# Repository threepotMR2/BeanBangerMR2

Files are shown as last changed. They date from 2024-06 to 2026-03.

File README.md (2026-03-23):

BeanBangerMR2
=============

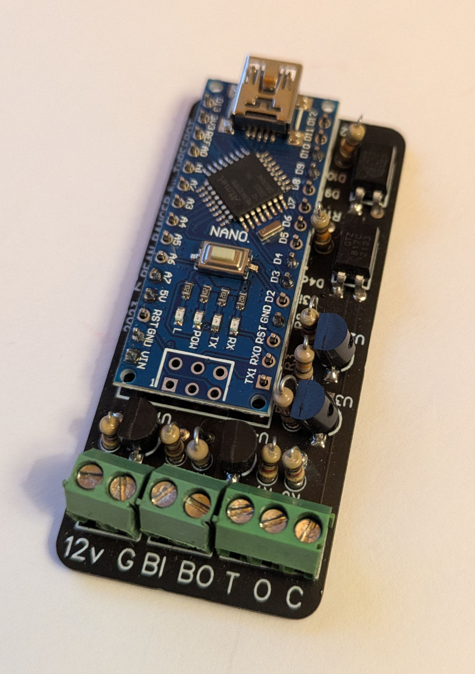
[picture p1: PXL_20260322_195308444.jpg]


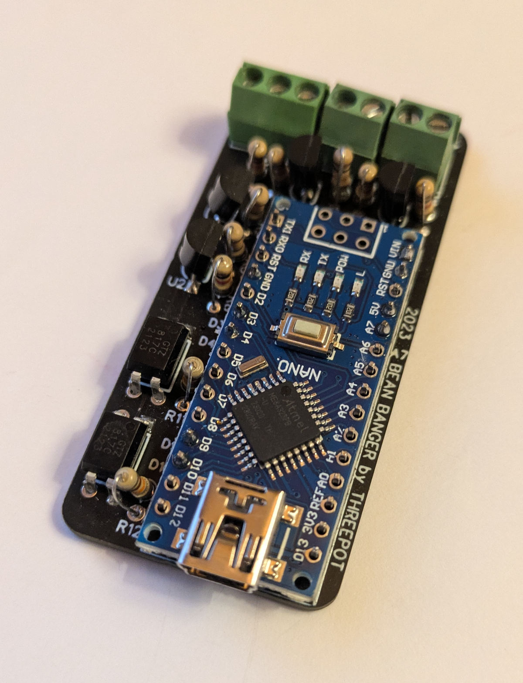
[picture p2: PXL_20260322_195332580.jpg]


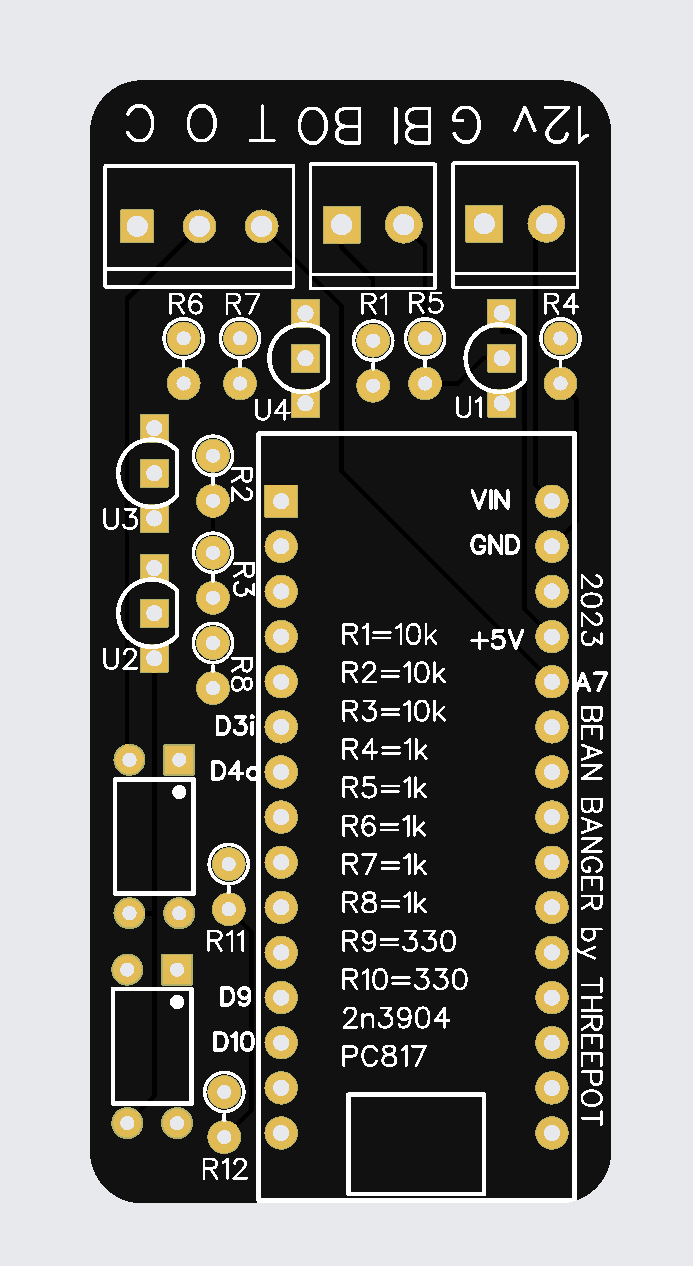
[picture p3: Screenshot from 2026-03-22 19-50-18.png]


This is an adaption/fork for the BeanMPX project by fiztech-code - thank you for amazing work, this would not exist without you. I have no idea what I'm doing but have butched the BeanMPX project to make this do what it should. It is probably the worst code man has seen, and I am probably using Github in totally the wrong way. Please forgive my stupidity and ignorance!

All you need is in the BeanBangerMR2 folders, one is the arduino project, the other is the gerber/bom for the PCB.

1) Simply upload the gerber to pcbway or jlcpcb and get some made for peanuts.
2) The list of components you need is printed on the circuit board and its all though hole easy soldering
3) upload the arduino sketch to the arduino nano
4) wire in the wire from the alternator charge sense line, the oil pressure switch, take a spur from the temp sensor, 12v, ground and the bean wires (either way doesn't matter).

Then as soon as you turn on the car, the warning lights will works and the temp gauge works.

Here is some testing video footage and description of usage:-
https://www.youtube.com/watch?v=NijV0-c2hg0

You will see it completed here:-
https://www.youtube.com/shorts/5FSTMIWvpoY

There is a very messy spreadsheet that "helps" to make the formula for to convert the analogue input voltage to the BEAN temp hex value for the arduino sketch so you can calibrate it for different temp sensors and ecu combinations.

Enjoy! 

ThreepotMR2

Components list:-

3 x 10k resistors
5 x 1k resistors
2 x 330 ohm resistors
4 x 2n3904 transistors
2 x PC817 optocouplers
1 x arduino nano
Some 2.54mm pitch PCB Mount Screw Terminal blocks ... or just solder your wires direct to the PCB

How To wire it in
=================

Inside the cluster the MPX1 and MPX2 wires are both joined together, so you can use either or both! The do the same thing.

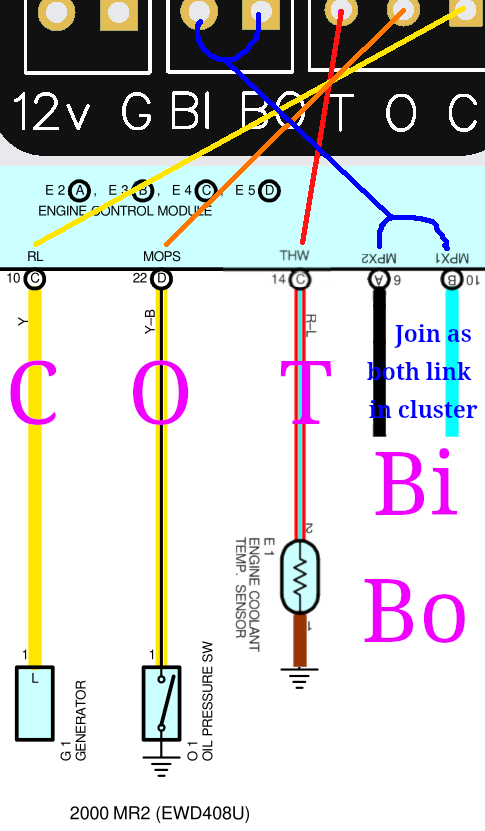
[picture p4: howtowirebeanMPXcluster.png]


This diagram shows you what each wire to use from the MR2 engine ecu connector.

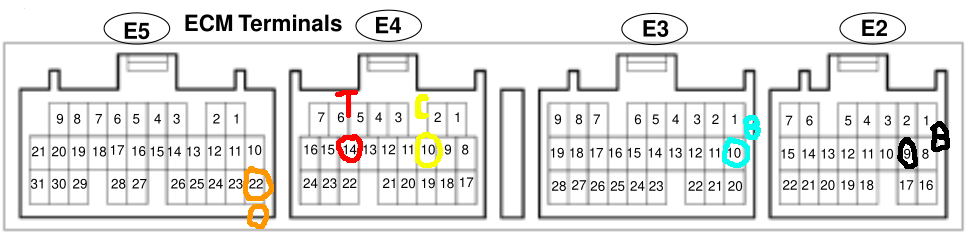
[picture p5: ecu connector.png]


BUT it you need to wire the temp sensor to your current ECU, which has a pullup resistor in it and thus the beanbanger works if you pull a spur from your temp sensor. e.g. your temp sensor will be feeding both the beanbanger and your engine ecu. The temp gauge calibration supplied in the arduino code is for Ecumaster Emu Black which has a 2.2k pull up resistor.

How To Calibrate te temp gauge algo for different sensor and ecu combinations
=============================================================================

In the "BeanBanger_works.ino" file this is this bit of code on lines 42 to 45

      //Does the temp gauge Algo is 75000/(ADC+300)).... ADC 0-1023 is 0-5v
      //Engine Temp Gauge moves 90-255 but normal range deadzone 165-212
      t = analogRead(A7);  //read temp sensor voltage on analogue pin 2  
      t = 75000/(t+300);

We are reading the analog value from the ADC Value from arduino input pin "A7", then we do a bit of maths on it:-

75000 / ( ADC value + 300) = bean temp value

You can play with this maths to create a value which ranges from 90 to 255 which is the gauge needle possition.

So roughly Degrees C x 2 = Bean value ......... e.g. 90c x 2 = 180 = which is in the "dead zone" being normal.

Its weird though, the first value that makes it move is 45c (90 bean) then upto 165 bean (82c) upto the middle of the gauge, then there is a deadzone from 165 to 212 which is normal temperature, then if you go about this the needle shoots up quickly. Its not a direct gauge, its more of an needle based normal/overheating dash indicator.

The deadzone starts at 82.5c (165 bean) and goes upto 106c (212 bean) which is pretty reasonable. Anything above this makes the gauge shoot up, e.g 107c = 214 bean

There is a spreadsheet here called temp gauge algo.ods https://github.com/threepotMR2/BeanBangerMR2/blob/master/temp%20gauge%20algo.ods which is an absolute utter mess but if you play with it you will see it draws you some graphs and will let you experiement with your algo, it is truly an utter mess though.

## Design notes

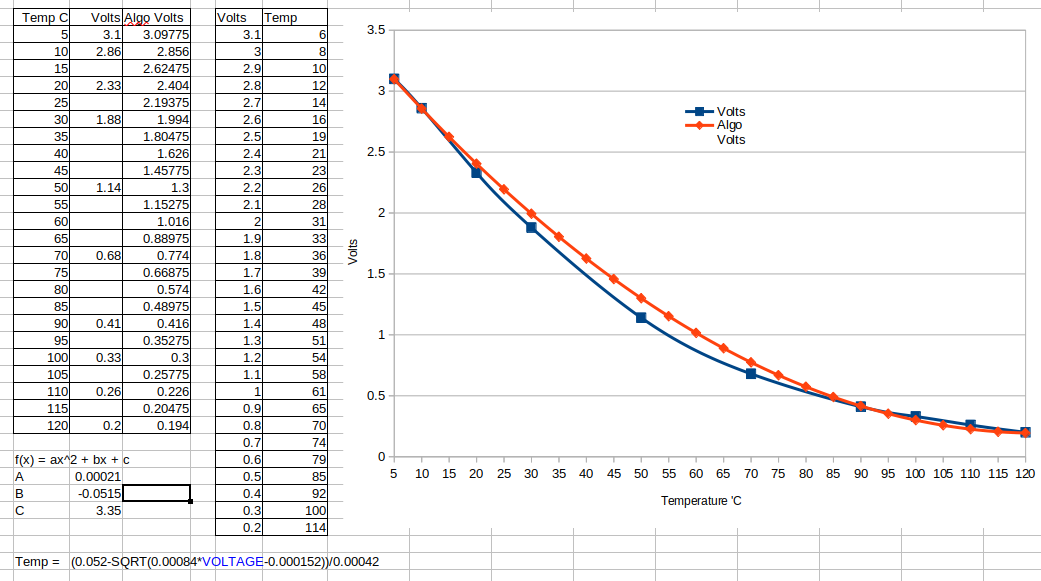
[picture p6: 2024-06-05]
arduino_code/Screenshot at 2022-05-16 12-52-23.png

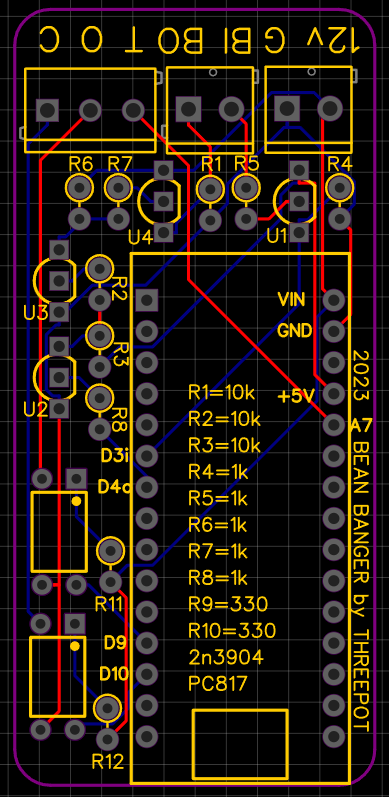
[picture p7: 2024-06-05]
PCB_Gerber/PCB.png

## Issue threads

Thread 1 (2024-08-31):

Unrelated Haldex

chrisgotboost, 2024-08-31:

threepotMR2, 2024-09-01:
What do you need?

chrisgotboost, 2024-09-01:
I need to test my software for flashing haldex. Since i was not able to hook my miniwingler to restore in case of crash. I have like 3 haldex modules. Would be very appreciated !

Envoyé de mon iPhone

Le 1 sept. 2024 à 07:23, threepotMR2 ***@***.***> a écrit :

What do you need?

—
Reply to this email directly, view it on GitHub<https://github.com/threepotMR2/BeanBangerMR2/issues/1#issuecomment-2323296129>, or unsubscribe<https://github.com/notifications/unsubscribe-auth/AEF5J2HGKKQFMCRYGLGPCATZUL2LDAVCNFSM6AAAAABNNQKMG6VHI2DSMVQWIX3LMV43OSLTON2WKQ3PNVWWK3TUHMZDGMRTGI4TMMJSHE>.
You are receiving this because you authored the thread.Message ID: ***@***.***>

threepotMR2, 2024-09-01:
What is your software? is it a fork from vw_flash?

chrisgotboost, 2024-09-01:
No, its a pc software, Its not made of python at all.

Thanks
Chris

Envoyé de mon iPhone

Le 1 sept. 2024 à 08:56, threepotMR2 ***@***.***> a écrit :

What is your software? is it a fork from vw_flash?

—
Reply to this email directly, view it on GitHub<https://github.com/threepotMR2/BeanBangerMR2/issues/1#issuecomment-2323329138>, or unsubscribe<https://github.com/notifications/unsubscribe-auth/AEF5J2AJ4EDCCA2QSNFBB7DZUMFGXAVCNFSM6AAAAABNNQKMG6VHI2DSMVQWIX3LMV43OSLTON2WKQ3PNVWWK3TUHMZDGMRTGMZDSMJTHA>.
You are receiving this because you authored the thread.Message ID: ***@***.***>

threepotMR2, 2024-09-01:
Is it just for VAG or do other brands too?
Yes I'll try at, as long as its not going to brick to many units!

chrisgotboost, 2024-09-01:
For now its a VAG flasher, but would be cool to add volvo as well, let me know what is best way to communicate other than here.

Thanks
Chris

Envoyé de mon iPhone

Le 1 sept. 2024 à 12:00, threepotMR2 ***@***.***> a écrit :

Is it just for VAG or do other brands too?
Yes I'll try at, as long as its not going to brick to many units!

—
Reply to this email directly, view it on GitHub<https://github.com/threepotMR2/BeanBangerMR2/issues/1#issuecomment-2323406971>, or unsubscribe<https://github.com/notifications/unsubscribe-auth/AEF5J2A6N7ICMITILS3NWQTZUM2ZHAVCNFSM6AAAAABNNQKMG6VHI2DSMVQWIX3LMV43OSLTON2WKQ3PNVWWK3TUHMZDGMRTGQYDMOJXGE>.
You are receiving this because you authored the thread.Message ID: ***@***.***>

threepotMR2, 2024-09-02:
Problem is, even with a miniwiggler, if you screw up the boot loader blocks the unit is bricked.

Have you actually tried it yourself?

chrisgotboost, 2024-09-02:
Hi !

If you take a full backup you can’t recover ? How do you screw bootloader, i never flashed one yet, i was told if the flash crash or whatever its not recoverable from UDS, need to be miniwingler.

I could be wrong

Tanks
Chris
Envoyé de mon iPhone

Le 2 sept. 2024 à 03:49, threepotMR2 ***@***.***> a écrit :

Problem is, even with a miniwiggler, if you screw up the boot loader blocks the unit is bricked.

Have you actually tried it yourself?

—
Reply to this email directly, view it on GitHub<https://github.com/threepotMR2/BeanBangerMR2/issues/1#issuecomment-2324048239>, or unsubscribe<https://github.com/notifications/unsubscribe-auth/AEF5J2BCWQWN7N3VU7DFLV3ZUQJ7ZAVCNFSM6AAAAABNNQKMG6VHI2DSMVQWIX3LMV43OSLTON2WKQ3PNVWWK3TUHMZDGMRUGA2DQMRTHE>.
You are receiving this because you authored the thread.Message ID: ***@***.***>

threepotMR2, 2024-09-02:
I have bricked about 10 Gen 5 VAG haldex controllers with the miniwiggler !

chrisgotboost, 2024-09-02:
So can we talk elsewhere than here ? ahaha

Thanks
Chris
Envoyé de mon iPhone

Le 2 sept. 2024 à 12:58, threepotMR2 ***@***.***> a écrit :

I have bricked about 10 Gen 5 VAG haldex controllers with the miniwiggler !

—
Reply to this email directly, view it on GitHub<https://github.com/threepotMR2/BeanBangerMR2/issues/1#issuecomment-2325104183>, or unsubscribe<https://github.com/notifications/unsubscribe-auth/AEF5J2FC6DDIBPPSW5EOONTZUSKKPAVCNFSM6AAAAABNNQKMG6VHI2DSMVQWIX3LMV43OSLTON2WKQ3PNVWWK3TUHMZDGMRVGEYDIMJYGM>.
You are receiving this because you authored the thread.Message ID: ***@***.***>

chrisgotboost, 2024-09-04:
@threepotMR2 ?

threepotMR2, 2024-09-04:
I can't be in the middle of you testing your software.
Firstly I don't have Gen 5 controllers to brick.
And I don't have the time to push your project forwards.
I can't help you with this sorry.

Closed 2024-09-04.

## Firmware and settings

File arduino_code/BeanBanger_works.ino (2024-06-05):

#include "BeanMPX.h"
#define RX_BUFFER_SIZE 20
BeanMPX bean;

uint8_t engTemp[]  =  {0x62, 0x2C, 0x00}; // Engine Temp 90-255 deadzone 165-212
uint8_t lights[] = {0x62, 0xD4, 0x00}; // BATT, OIL --11---- (32,16) 
uint32_t timer = 0;
uint32_t current_millis = 0;
uint8_t bean_rx_buffer[RX_BUFFER_SIZE];
uint8_t bean_rx_index = 0;
uint8_t g = 1;
float t = 0;

void setup() {
  pinMode(9, INPUT_PULLUP);     //Oil Pressure Light
  pinMode(10, INPUT_PULLUP);     //Charge Light
  Serial.begin(115200);
  while (!Serial) {;}  
  bean.begin(8, 9); //RX pin, TX pin
}

void loop() { 
  current_millis = millis();
  if (bean.available()) {
   bean.getMsg(bean_rx_buffer, RX_BUFFER_SIZE);
    Serial.print((char)bean_rx_buffer[1]); 
    Serial.print(" ");
   for (int i = 2; i < bean_rx_buffer[0]+2; i++) {
      if (bean_rx_buffer[i] < 0x10) {
        Serial.print(0, HEX); 
      }
      Serial.print(bean_rx_buffer[i], HEX); 
      Serial.print(" ");    
    }    
    Serial.print("\n");    
    memset(bean_rx_buffer, 0, RX_BUFFER_SIZE); 
   }  
    if (current_millis - timer > 1000) {
    if (!bean.isBusy()) {  

             
//Does the temp gauge Algo is 75000/(ADC+300)).... ADC 0-1023 is 0-5v
//Engine Temp Gauge moves 90-255 but normal range deadzone 165-212
      t = analogRead(A7);  //read temp sensor voltage on analogue pin 2
      t = 75000/(t+300);
      engTemp[2] = t;
      if (engTemp[2]==213){engTemp[2]=214;} // fixes weird needle drop at 213h
      bean.sendMsg(engTemp, sizeof(engTemp));
      Serial.print(analogRead(A2));
      Serial.print(" ADC is hex value "); 
      Serial.print(engTemp[2]);
      Serial.print("\n");

      delay(50);
           
//Does the warning lights
      g = 0;  
      if (digitalRead(9) ==LOW){g=g+16;}   //Oil Pressure Light
      if (digitalRead(10) ==LOW){g=g+32;}   //Charge Light
      lights[2] = g;    
      bean.sendMsg(lights, sizeof(lights));
      Serial.print(digitalRead(9));
      Serial.print(" OILd11 - BATTd12 "); 
      Serial.print(digitalRead(10));
      Serial.print("\n");   

      timer = current_millis;
    }  
      
  } 
}

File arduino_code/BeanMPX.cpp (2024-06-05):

// 
// Includes
//
#include <Arduino.h>
#include "BeanMPX.h"

//
// Statics
//
BeanMPX *BeanMPX::active_object = 0;
BeanMPX *BeanMPX::active_object2 = 0;

#ifdef _DEBUG
uint8_t debug_pin1 = (1<<PD3); // pin 3
uint8_t debug_pin2 = (1<<PD4); // pin 4
uint8_t debug_pin3 = (1<<PD5); // pin 5
#endif


//
// CRC
//
uint8_t BeanMPX::gencrc(uint8_t bytes[], uint8_t length) { // calculate CRC by byte
  uint8_t crc = 0;
  for (uint8_t i = 0; i < length; i++) {
    uint8_t b = bytes[i];
    /* XOR-in next input byte */
    uint8_t data = (b ^ crc);
    /* get current CRC value = remainder */    
	crc = pgm_read_word_near(crctable + data);
  }
  return crc;
}

uint8_t BeanMPX::checkcrc(uint8_t bytes[], uint8_t length) {
  uint8_t crc = 0;
  for (uint8_t i = 1; i < length; i++) { // skips SOF 
    uint8_t b = bytes[i];
    uint8_t data = (b ^ crc);    
	crc = pgm_read_word_near(crctable + data);
  }  
  return crc;
}

//
// Receive helpers
//
void BeanMPX::storeReceivedBit(uint8_t rx_pin_val, bool no_stuffing_bit = false) {
  if (no_stuffing_bit) {
    if (rx_pin_val) {
      d |= i;
    }

    i >>= 1;
    return;
  }

  if (s0 == 5 || s1 == 5) { // skip stuffing bit
    i <<= 1;
  } else {
    if (rx_pin_val) {
      d |= i;
    }
  }

  if (rx_pin_val) {
    s0++;
    s1 = 0;
  } else {
    s1++;
    s0 = 0;
  }

  i >>= 1;
}

void BeanMPX::storeReceivedByte() {  
  _receive_buffer[_buffer_index] = d;   
  d = 0;
  i = 0x80;
  _buffer_index++;
  if (_buffer_index > BUFFER_SIZE) {
	_buffer_index = 0;
	is_listining = false;
	msg_stage = 0;	  
  }    
}

void BeanMPX::storeMessage(uint8_t *msg, uint8_t len, uint8_t msg_type) { // Store Message to mailbox
  if (mailbox_fill_level < MAILBOX_SIZE) {
	mailbox[mailbox_fill_level][0] = len;
	mailbox[mailbox_fill_level][1] = msg_type;
	memcpy(&mailbox[mailbox_fill_level][2], msg, len);
	mailbox_fill_level++;
  }
}

void BeanMPX::getMsg(uint8_t *buffer, uint8_t buffer_len) {	
	memcpy(buffer, mailbox[0], buffer_len); // get first from mail box
	
	for (int i = 0; i < mailbox_fill_level && i < MAILBOX_SIZE; i++) { // shift all messages up
		memcpy(mailbox[i], mailbox[i+1], BUFFER_SIZE);
	}
	if (mailbox_fill_level > 0) {
		mailbox_fill_level--;
	}
}

uint8_t BeanMPX::getStatus() {	
	return mailbox_fill_level;
}


//
// The receive routine called by the interrupt handler
//
void BeanMPX::receive() {
  if (is_transmitting) {
    return;
  }
  
  if (s0 > 7 || s1 > 7) {
	_buffer_index = 0;
	is_listining = false;
	msg_stage = 0;	
	s0 = 0;
	s1 = 0;
	return;
  } 

  uint8_t rx_pin_val;
  rx_pin_val = *_receivePortRegister & _receiveBitMask;

  switch (msg_stage) {
    case 0:
      storeReceivedBit(rx_pin_val, true);

      if (!i) {
        d &= 1;
        storeReceivedByte();
        msg_stage++;
      }
      break;
    case 1:
      storeReceivedBit(rx_pin_val);

      if (!i) {
        msg_length = d & 0x0f;
        if (msg_length > 13) {
          msg_stage = 0;
          is_listining = false;

          *_timerInterruptMaskRegister = 0; // disable timer interrupts

          _buffer_index = 0;
        }
        storeReceivedByte();
        msg_stage++;
        break;
      }
      break;
    case 2:
      storeReceivedBit(rx_pin_val);

      if (!i) {
        storeReceivedByte();
        if (msg_length == 1) {
          msg_stage++;
          break;
        }
        msg_length--;
      }
      break;
    case 3:
      storeReceivedBit(rx_pin_val);

      if (!i) {
        storeReceivedByte();
        s0 = 0;
        s1 = 0;
        msg_stage++;
        break;
      }
      break;
    case 4:
      storeReceivedBit(rx_pin_val, true);
      if (!i) {
        if (checkcrc(_receive_buffer, _buffer_index) == 0) {
          ack = 0x40;
        }
        else {
          ack = 0x80;
        }
        if (d == 0x7E) {
          for (int a = 0; a < sizeof(acknowledge_did); a++) {
            if (_receive_buffer[2] == acknowledge_did[a]) {
              is_transmit_ack = true;
              a = sizeof(acknowledge_did);
            }
          }
        }
        storeReceivedByte();
        msg_stage++;
        break;
      }
      break;
    case 5:
      storeReceivedBit(rx_pin_val, true);

      if (!i || (i & 0x1f) > 0) {
        storeReceivedByte();

        *_timerInterruptMaskRegister = 0; // disable timer interrupt

        msg_stage = 0;
        is_listining = false;
		busy_timeout = millis();

        storeMessage(_receive_buffer, _buffer_index, 'R');
        _buffer_index = 0;

        break;
      }
      break;
  }
}

void BeanMPX::receiveAcknowledge() {
  if (!is_receive_ack) return;

  uint8_t rx_pin_val;
  rx_pin_val = *_receivePortRegister & _receiveBitMask;

  if (rx_pin_val) {
    rsp |= k;
  }

  k >>= 1;

  if (!k) {
    k = 0x80;
	
	_transmit_buffer[_tx_buffer_index] = rsp;
	storeMessage(_transmit_buffer, _tx_buffer_index + 1, 'T');	

    if (rsp != 0x40 && tx_retry) {
      _tx_buffer_index = 0;
      j = 1;
      tx_retry--;
    } else {
      _tx_buffer_len = 0;
      tx_retry = 2;
    }
    is_receive_ack = false;
	busy_timeout = millis();
    rsp = 0;    
  }
}


//
// The transmit routine called by the interrupt handler
//
void BeanMPX::transmit() {
  if (!(_tx_buffer_index < _tx_buffer_len)) {
    if (_tx_buffer_len > 1) {
      is_receive_ack = true;
      return;
    } else {
      if (is_transmitting) {
        is_transmitting = false;
		busy_timeout = millis();
        if (!is_listining) {
          *_timerInterruptMaskRegister = 0; // disable timer interrupt
        }
        txSafetyState(); // safety
      }
      return;
    }
  }

  is_transmitting = true;

  uint8_t tx_pin_val;
  tx_pin_val = _transmit_buffer[_tx_buffer_index] & j;

  if (_tx_buffer_index < _tx_buffer_len - 1 && (tx_s0 == 5 || tx_s1 == 5)) {
    j <<= 1;
    if (tx_s0 == 5) {
	  tx_pin_val = 0; // bug fix to count stuffing bit	 
	  *_transmitPortRegister &= ~_transmitBitMask;
    } else {	  
	  tx_pin_val = 1; // bug fix to count stuffing bit
	  *_transmitPortRegister |= _transmitBitMask; 
    }
  } else {	  
	if (tx_pin_val) {
	  *_transmitPortRegister |= _transmitBitMask;
    } else {      	  
	  *_transmitPortRegister &= ~_transmitBitMask;
    }    
  }

  if (tx_pin_val) {
    tx_s0++;
    tx_s1 = 0;
  } else {
    tx_s1++;
    tx_s0 = 0;
  }

  j >>= 1;
  if (!j) {
    j = 0x80;
    _tx_buffer_index++;
  }
}

void BeanMPX::transmitAcknowledge() {
  if (!is_transmit_ack) {
    return;
  }
  
  uint8_t tx_pin_val;
  tx_pin_val = ack & l;
   
  
  if (tx_pin_val) {
	*_transmitPortRegister |= _transmitBitMask;
  } else {
	*_transmitPortRegister &= ~_transmitBitMask;   	
  }  

  l >>= 1;
  if (!l || (l & 0x1f) > 0) {
    is_transmit_ack = false;
	busy_timeout = millis();
    l = 0x80; 
	txSafetyState(); // safety
  }
}
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
